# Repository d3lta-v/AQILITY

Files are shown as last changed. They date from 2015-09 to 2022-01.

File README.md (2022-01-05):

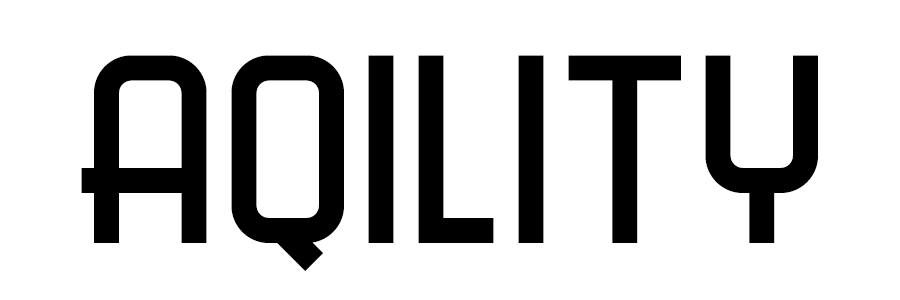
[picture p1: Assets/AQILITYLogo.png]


by StatiX Electromechanics, a subsidiary company of [StatiX Industries](https://statixind.net)

# AQILITY (Air Quality Acquisition Ability)

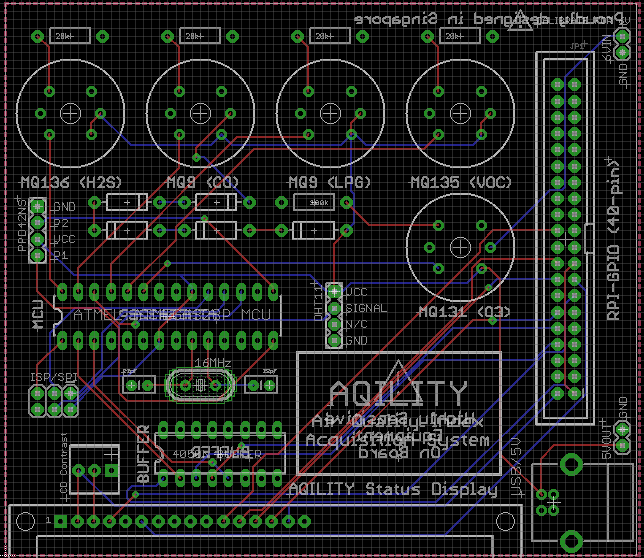
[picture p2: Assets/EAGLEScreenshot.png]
AQILITY


This is the open source version of the AQILITY, the free, crowd-sourced software and hardware platform for air quality detection and the upload of data to the cloud. We were simply people who thought we could do something about the Singapore/Indonesian transboundary haze, and this is what we've made. Enjoy!

#### How to access live data from the currently deployed sensor:

**Live** data which is processed by the MATLAB program included in this repo can be accessed on ThingSpeak [here](https://thingspeak.com/channels/56281). NOTE: The picture below is NOT the actual live data.

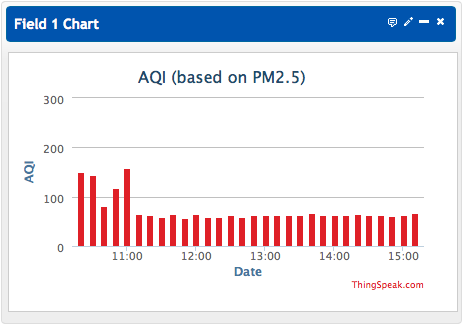
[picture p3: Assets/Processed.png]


Raw data (which may have errors) can be accessed [here](https://thingspeak.com/channels/31799), below is a sample of what to expect (this data is unprocessed and flawed, so please do not use this as official readings).

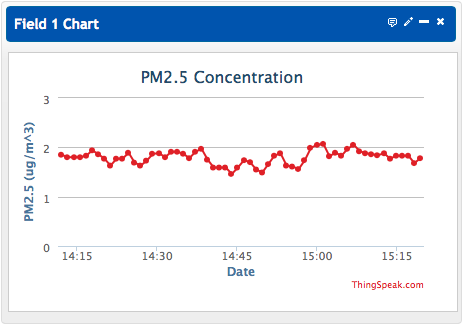
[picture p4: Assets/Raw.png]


The AVR subsysem of this system uses a forked version of the [DustDuino](http://publiclab.org/wiki/dustduino) code base (licensed under the CC BY-SA 3.0 license) for an Arduino-compatible particulate sensing system. Big props to them for doing the best work in the world.

## Description:
This system collects real time data from the air with several onboard sensors and relays the data from the microcontroller to the Raspberry Pi which caches all the data collected. This data is periodically uploaded onto the ThingSpeak platform, which is then analysed by the MATLAB code and the new data inserted into another ThingSpeak channel to display the actual values.

The calculation from ug/m<sup>3</sup> to official AQI is a piecewise linear function provided by the EPA (research paper [here](http://www3.epa.gov/ttn/oarpg/t1/memoranda/rg701.pdf)). The system provides an LCD screen to display live unprocessed values for easy monitoring.

A full flowchart of the system can be seen as below:

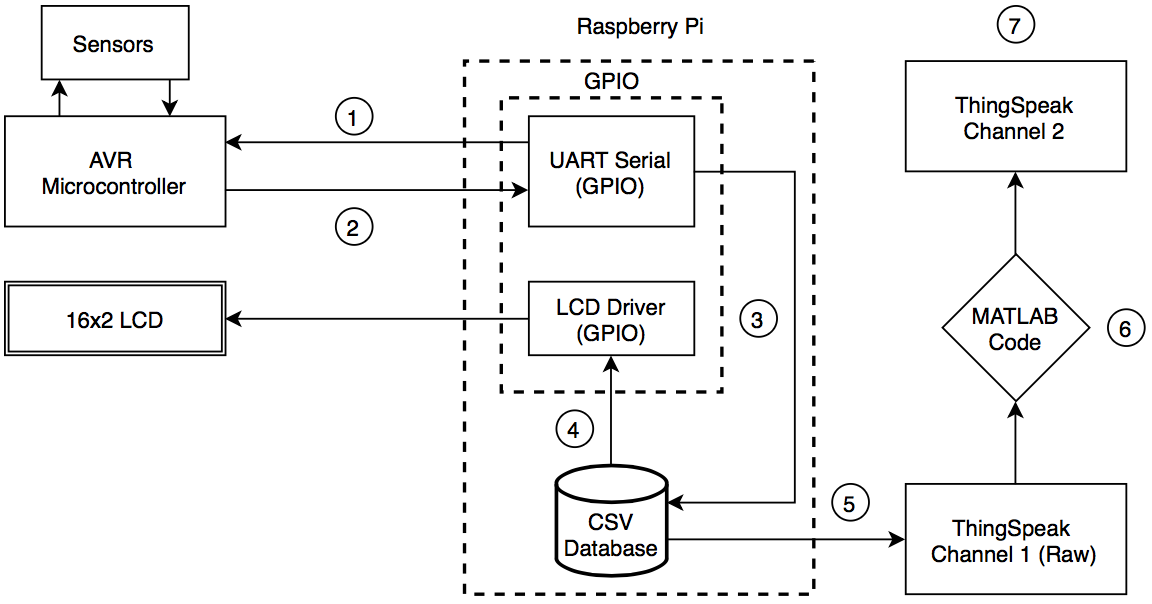
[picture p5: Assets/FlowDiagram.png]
Flowchart


1. Raspberry Pi sends a single unique character (a single dot, ".", ASCII code 46) to the microcontroller
2. Microcontroller has a cached copy of all the recent data taken over a certain timeframe and sends the cached data to the Pi. This data is already formatted in the CSV format.
3. Pi saves the data from the microcontroller into a CSV database.
4. The CSV database is read by another program and the data fed into the LCD driver on the GPIO to display air quality parameters on the LCD
5. Simultaneously, this data is sent by a HTTP POST request to the first ThingSpeak channel, which contains unprocessed data.
6. Data crunching takes place on the ThingSpeak platform with the MATLAB language, which calculates the correct AQI value using a piecewise linear function defined by the EPA.
7. The processed data is sent to the second ThingSpeak channel which houses all the processed data.

#### Features:

1. Has an LCD to display the air quality parameters dynamically on the sensor board itself
2. Automatically uploads air quality data to the cloud (ThingSpeak.com)
3. Relies on a Arduino-Raspberry Pi hybrid to achieve both long term data storage and better data transfer options such as through a cellular/3G USB dongle
4. Detects some of the most common airborne pollutants and chemicals (PM10, PM2.5, H2S, CO, VOCs) for the computation of the overall pollutant indices
5. The system has an initial waiting time, to wait for the AVR and the sensors to initialize and self-calibrate before taking readings.

## Availability:
This system is only tested on Raspberry Pis and the ATmega328P chip. There will be no guarentees that the same code (built on the Arduino platform) will run properly on other Arduino platforms or even on other AVRs such as the XMega series. The ribbon cable connector on the offical board is customized for Raspberry Pi + series ONLY, but you can manually pinout the connector for the old 28-pin GPIO.

## Author(s):
* Chief Designer; Programmer: Pan Ziyue
* R&D/Scientific Inquiry: Chow Zi Jie & Rachit Agrwal
* The awesome open source folks at Adafruit and the [DustDuino Development Team](http://publiclab.org/wiki/dustduino)

## Caveats:
* Requires for the Raspberry Pi's UART port on the GPIO to be freed. More info [here](http://www.hobbytronics.co.uk/raspberry-pi-serial-port)
* The code on the AVR seems to have a discrepancy of a factor of 10 for the PM2.5 concentration, which is then manually rectified by the MATLAB code. There may be a serious underlying problem with the original DustDuino code for the calculation of concentration, or lack of calibration of the sensor (which is supposed to be factory calibrated)
* The use of a Raspberry Pi enforces the use of a 5V/3.3V logic level shifter to avoid damaging the Pi.
* The gas sensors have NO calibration, which means that there is currently no logic implemented for the equation of output voltage of gas sensors to corresponding concentrations of gases.
* The Python code on the Raspberry Pi does not automatically archive or delete old data, and requires manual work to clear old data. This is a possible area of improvement and we welcome you to submit a pull request to implement such a feature.
* Dependencies must be manually installed and the GPIO port manually configured, which reduces code reusability and portability. Suggest making a single shell script to accomplish all of that.
* Python scripts must be pre-specified in `/etc/rc.local` for it to automatically start when the Raspberry Pi is booted up.

##  Dependencies:
* [Adafruit_Python_CharLCD](https://github.com/adafruit/Adafruit_Python_CharLCD)
* [DHT11 Library](http://playground.arduino.cc/Main/DHT11Lib)
* PySerial (install with `sudo pip3 install pyserial`)
* [httplib2](https://github.com/jcgregorio/httplib2)

## License:
<br />This work is licensed under a <a rel="license" href="http://creativecommons.org/licenses/by-sa/3.0/">Creative Commons Attribution-ShareAlike 3.0 Unported License</a>.

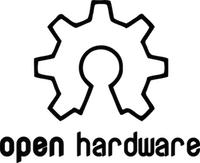
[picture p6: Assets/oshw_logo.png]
Open Source Hardware Initiative


Copyright (C) StatiX Industries 2014-2016

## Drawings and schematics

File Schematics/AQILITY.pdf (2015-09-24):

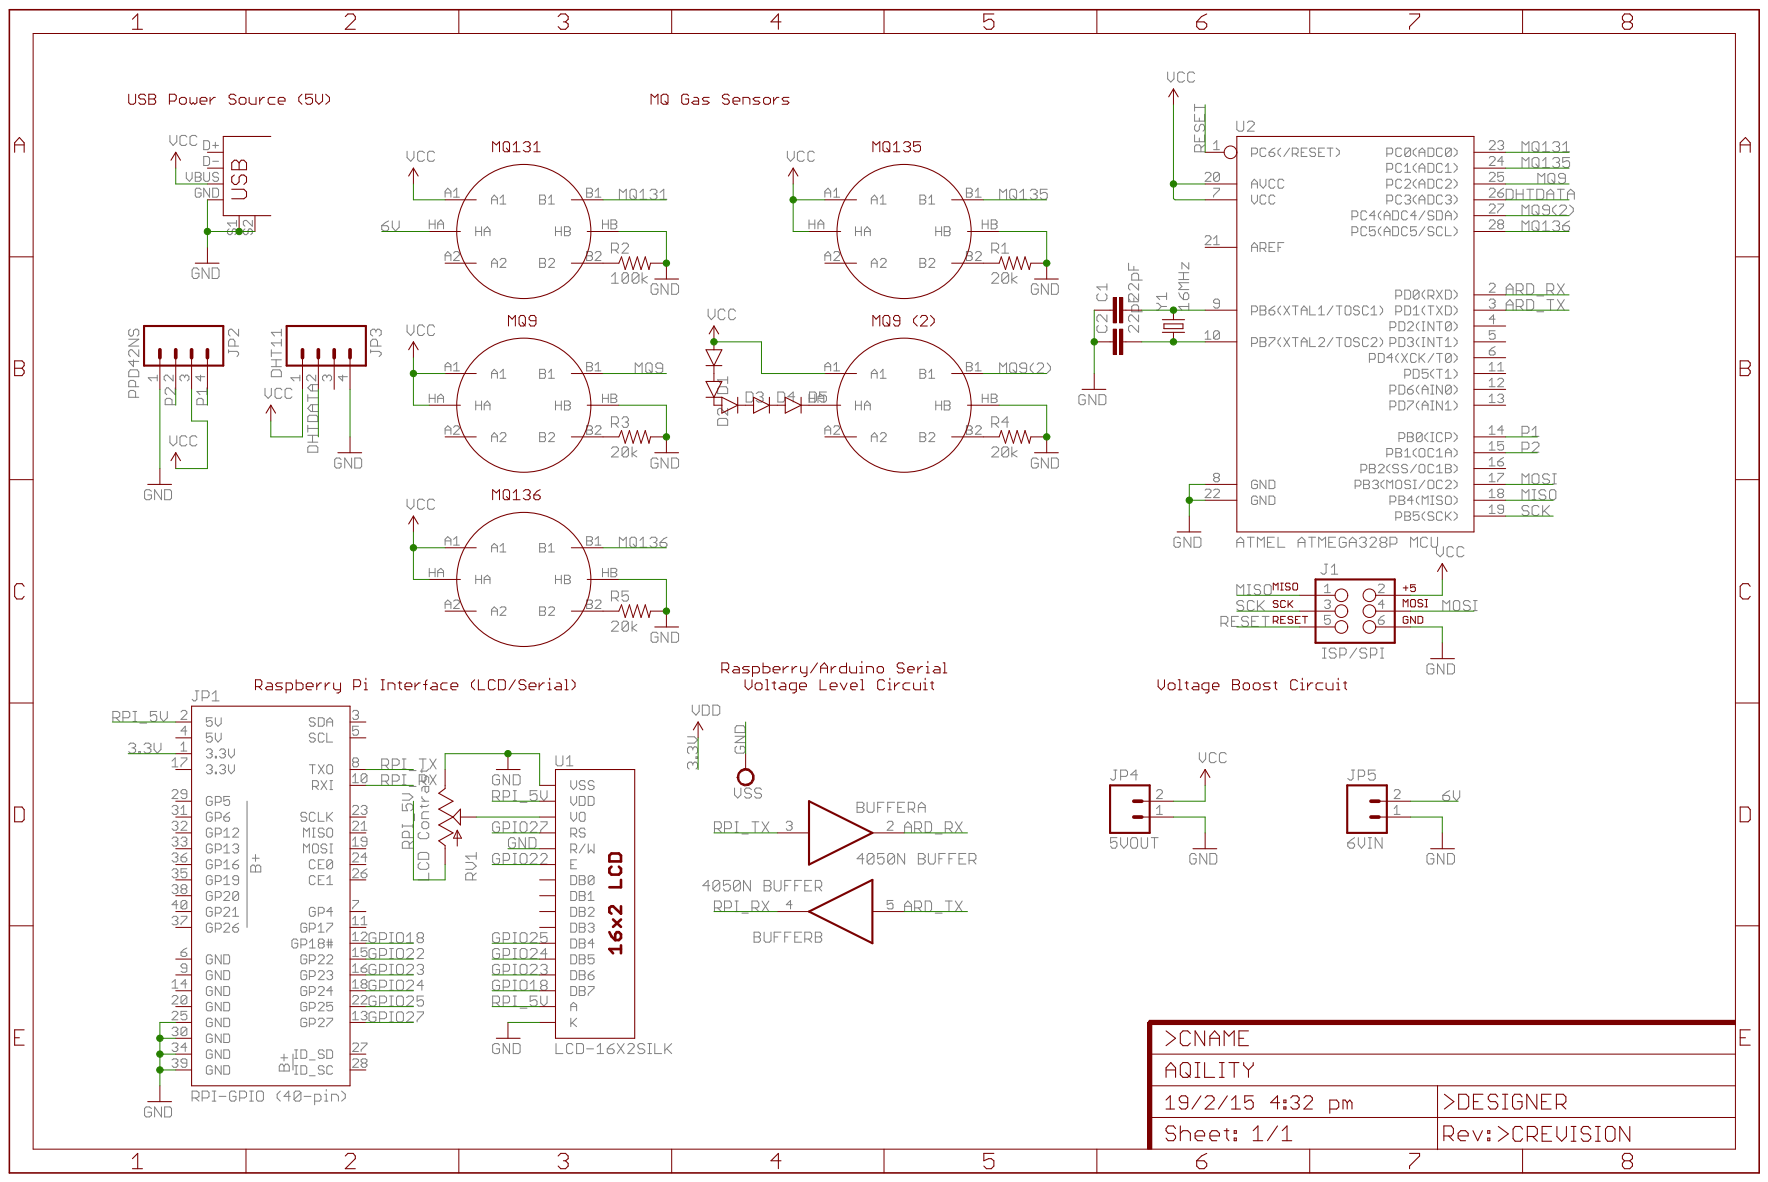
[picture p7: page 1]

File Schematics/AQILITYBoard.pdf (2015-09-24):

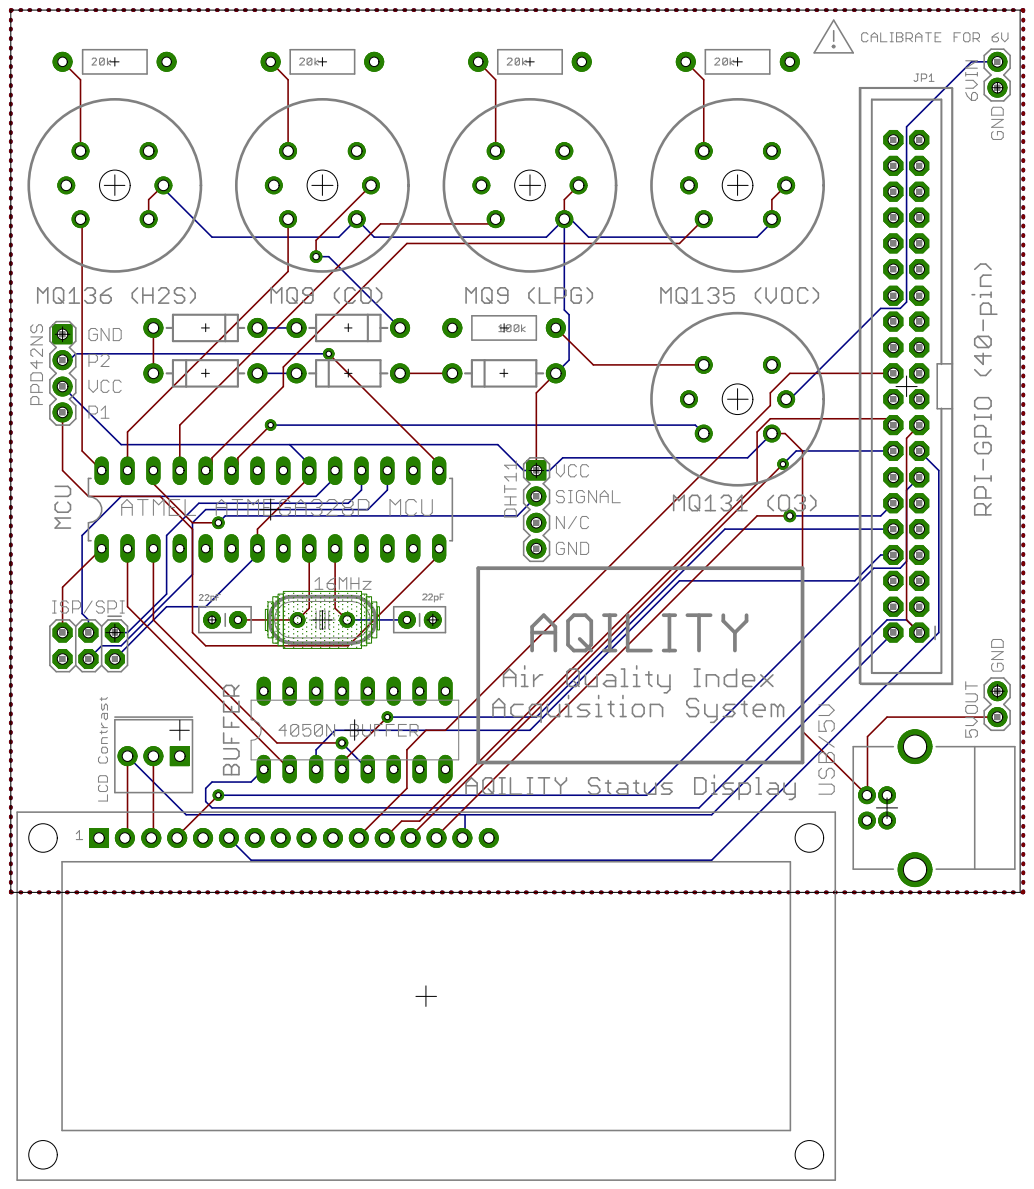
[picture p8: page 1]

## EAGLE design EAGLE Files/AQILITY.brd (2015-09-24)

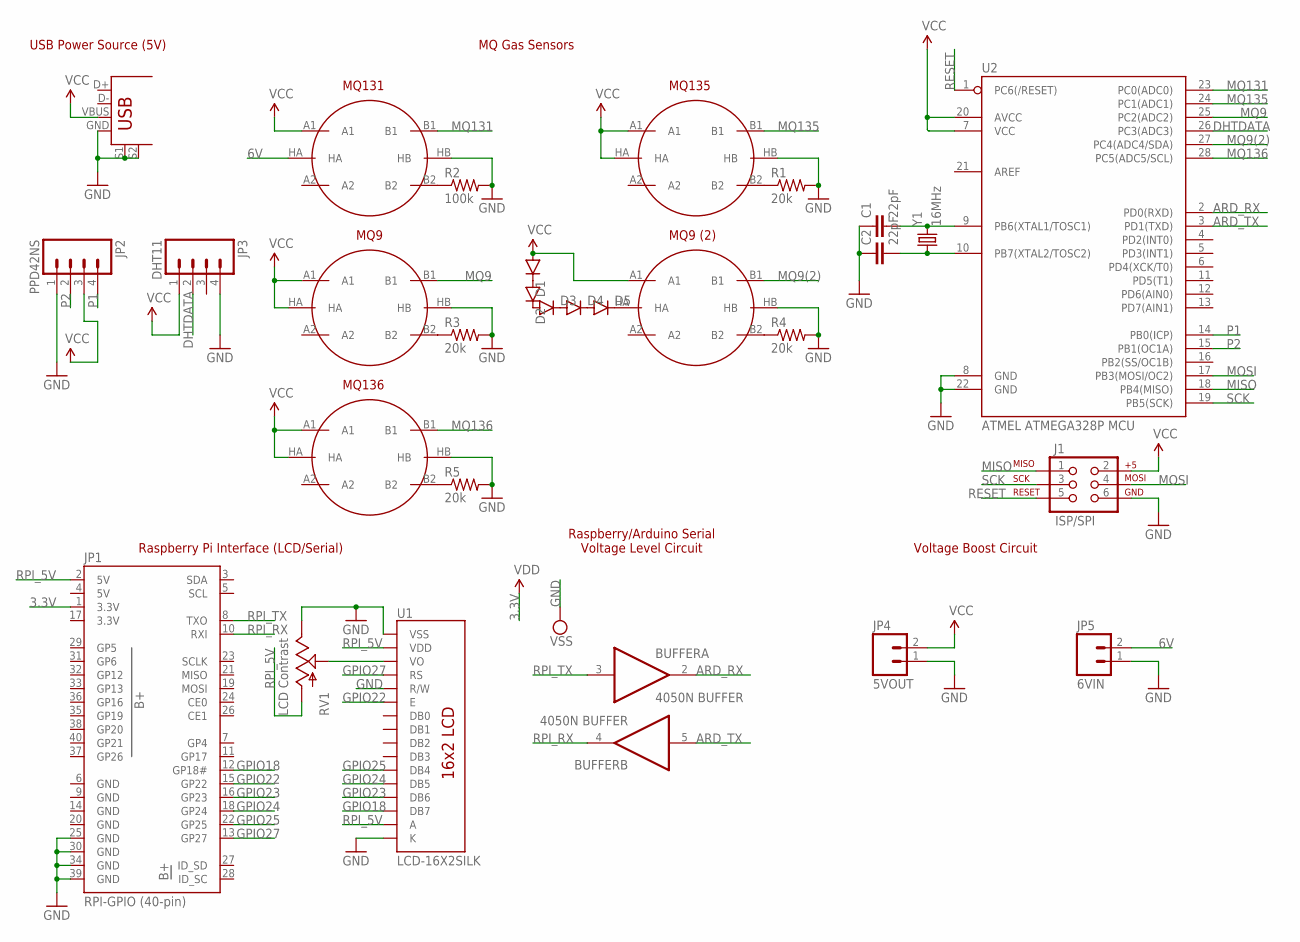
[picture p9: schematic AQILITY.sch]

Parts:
BUFFER: 4050N BUFFER; DIL16
C1, C2: 22pF; CAP-PTH-SMALLEZ
D1, D2, D3, D4, D5: DIODEKIT2; DIODE-1N4001-KIT
J1: ISP/SPI; 2X3
JP1: RPI-GPIO (40-pin); 2X20-SHROUDED
JP2: PPD42NS; 1X04
JP3: DHT11; 1X04
JP4: 5VOUT; 1X02
JP5: 6VIN; 1X02
MQ9, MQ9(2), MQ131, MQ135, MQ136: METHANE_SENSOR; MQ-3
R1, R3, R4, R5: 20k; AXIAL-0.4
R2: 100k; AXIAL-0.4
RV1: LCD Contrast; 3362U
U1: LCD-16X2SILK; LCD-16X2
U2: ATMEL ATMEGA328P MCU; DIL28-3
U$5: USB/5V; USB-B-PTH
Y1: 16MHz; HC49U-V

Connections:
3.3V: BUFFER.1 (VDD), JP1.1 (3.3V), JP1.17 (3.3V)
5V: JP1.4 (5V)
6V: JP5.2, MQ131.HA
ARD_RX: BUFFER.2 (O), U2.2 (PD0(RXD))
ARD_TX: BUFFER.5 (I), U2.3 (PD1(TXD))
DHTDATA: JP3.2, U2.26 (PC3(ADC3))
GND: BUFFER.8 (VSS), C1.1, C2.1, J1.6, JP1.6 (GND), JP1.9 (GND), JP1.14 (GND), JP1.20 (GND), JP1.25 (GND), JP1.30 (GND), JP1.34 (GND), JP1.39 (GND), JP2.1, JP3.4, JP4.1, JP5.1, MQ9.HB, MQ9(2).HB, MQ131.HB, MQ135.HB, MQ136.HB, R1.P$2 (2), R2.P$2 (2), R3.P$2 (2), R4.P$2 (2), R5.P$2 (2), RV1.P$1 (E), U1.1 (VSS), U1.5 (R/W), U1.16 (K), U2.8 (GND), U2.22 (GND), U$5.GND, U$5.S1, U$5.S2
GPIO18: JP1.12 (GP18#), U1.14 (DB7)
GPIO22: JP1.15 (GP22), U1.6 (E)
GPIO23: JP1.16 (GP23), U1.13 (DB6)
GPIO24: JP1.18 (GP24), U1.12 (DB5)
GPIO25: JP1.22 (GP25), U1.11 (DB4)
GPIO27: JP1.13 (GP27), U1.4 (RS)
MISO: J1.1, U2.18 (PB4(MISO))
MOSI: J1.4, U2.17 (PB3(MOSI/OC2))
MQ9: MQ9.B1, U2.25 (PC2(ADC2))
MQ9(2): MQ9(2).B1, U2.27 (PC4(ADC4/SDA))
MQ131: MQ131.B1, U2.23 (PC0(ADC0))
MQ135: MQ135.B1, U2.24 (PC1(ADC1))
MQ136: MQ136.B1, U2.28 (PC5(ADC5/SCL))
unnamed: RV1.P$2 (S), U1.3 (VO)
unnamed: C1.2, U2.9 (PB6(XTAL1/TOSC1)), Y1.2
unnamed: C2.2, U2.10 (PB7(XTAL2/TOSC2)), Y1.1
unnamed: D1.C, D2.A
unnamed: D2.C, D3.A
unnamed: D3.C, D4.A
unnamed: D5.C, MQ9(2).HA
unnamed: D4.C, D5.A
unnamed: MQ136.B2, R5.P$1 (1)
unnamed: MQ135.B2, R1.P$1 (1)
unnamed: MQ9.B2, R3.P$1 (1)
unnamed: MQ131.B2, R2.P$1 (1)
unnamed: MQ9(2).B2, R4.P$1 (1)
P1: JP2.4, U2.14 (PB0(ICP))
P2: JP2.2, U2.15 (PB1(OC1A))
RESET: J1.5, U2.1 (PC6(/RESET))
RPI_5V: JP1.2 (5V), RV1.P$3 (A), U1.2 (VDD), U1.15 (A)
RPI_RX: BUFFER.4 (O), JP1.10 (RXI)
RPI_TX: BUFFER.3 (I), JP1.8 (TXO)
SCK: J1.3, U2.19 (PB5(SCK))
VCC: D1.A, J1.2, JP2.3, JP3.1, JP4.2, MQ9.A1, MQ9.HA, MQ9(2).A1, MQ131.A1, MQ135.A1, MQ135.HA, MQ136.A1, MQ136.HA, U2.7 (VCC), U2.20 (AVCC), U$5.VBUS

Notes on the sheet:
MQ135
MQ131
MQ9
MQ9 (2)
MQ136
Voltage Boost Circuit
Raspberry Pi Interface (LCD/Serial)
MQ Gas Sensors
USB Power Source (5V)
Raspberry/Arduino Serial Voltage Level Circuit

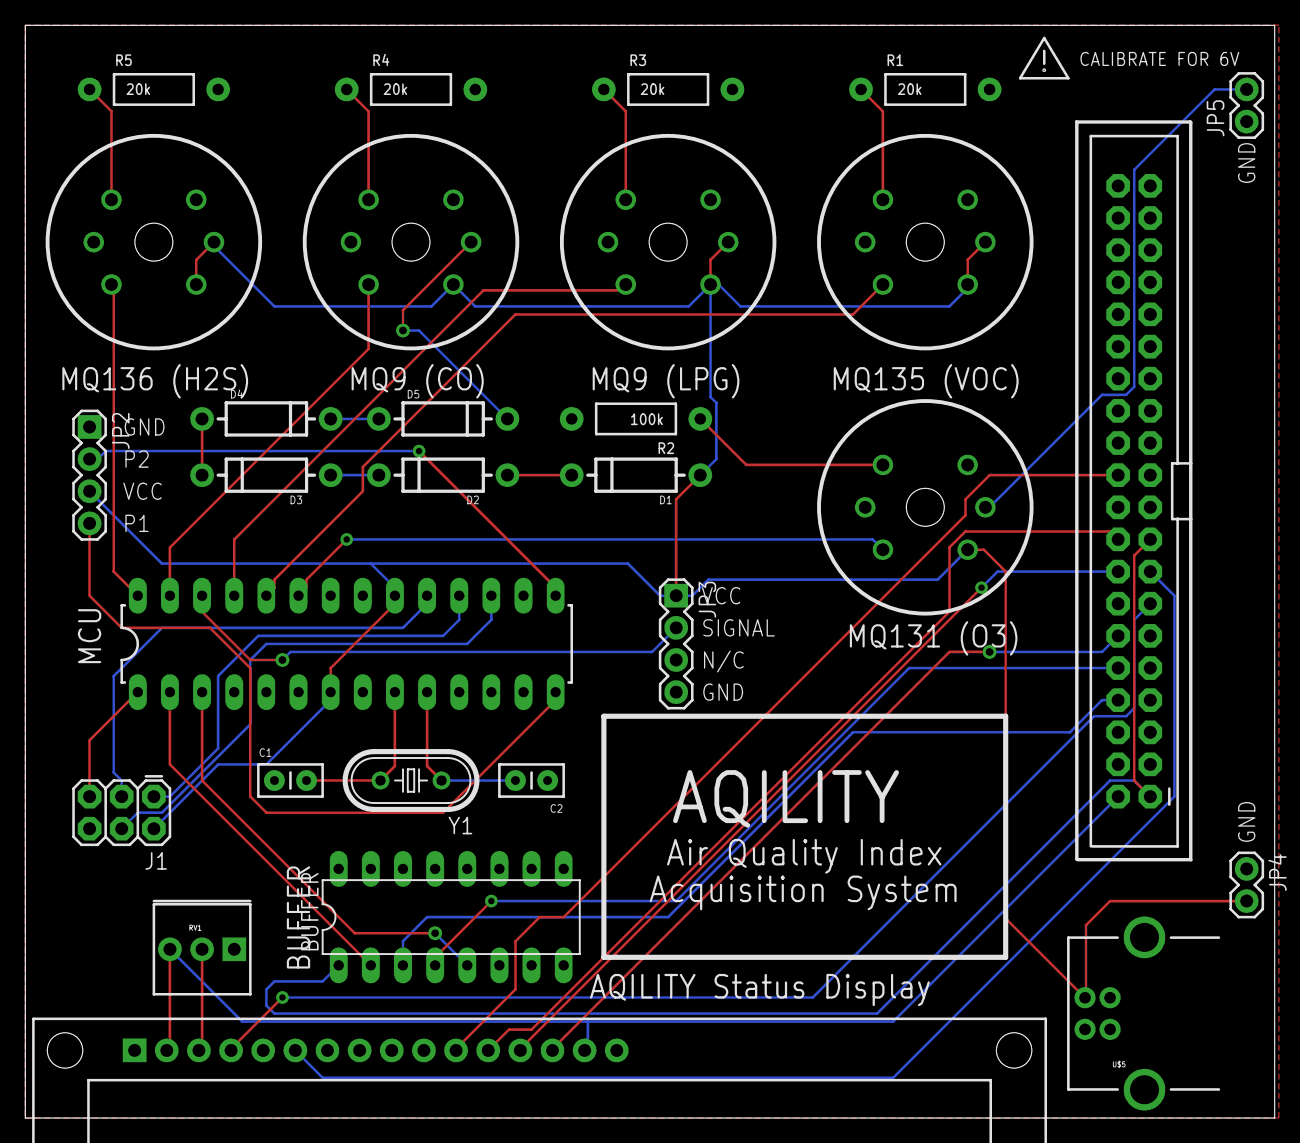
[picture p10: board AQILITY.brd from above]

Board: 2 copper layers, 98.7 x 86.3 mm, 29 parts (0 on the bottom side), 40 nets.

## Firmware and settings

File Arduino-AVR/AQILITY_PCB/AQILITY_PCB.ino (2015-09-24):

// 
// AQILITY (Air Quality Index Aquisition Ability)
// Created by Pan Ziyue and Chow Zijie 2014
// 

#include "dht11.h"

/* Start RainSensor/TempSensor */
const int numReadings = 10;
const int frequency = 1;    // How many probes per second?
const int caliOff = -10;

dht11 DHT11;
/* End RainSensor/TempSensor */

/* Start PinNames */
const int mq131Pin = A0;
const int mq135Pin = A1;
const int mq9Pin = A2; // Flammable gases
const int dhtPin = A3;
const int mq92Pin = A4; // Carbon monoxide
const int mq136Pin = A5; // Hydrogen Sulfide (H2S)
const int p1Pin = 8;
const int p2Pin = 9;
/* End PinNames */

/* Start SensorValues */
float mq131Voltage;
float mq135Voltage;
float mq9Voltage;
float mq92Voltage;
float mq136Voltage;

int humidityReadings[10];
int humidityIndex = 0;
int humidityTotal = 0;
int humidityAverage = 0;
float temperature = 0.0;
float humidity = 0.0;
/* End SensorValues*/

/* Start DustDuino Variable Import */
unsigned long starttime;

unsigned long triggerOnP1;
unsigned long triggerOffP1;
unsigned long pulseLengthP1;
unsigned long durationP1;
boolean valP1 = HIGH;
boolean triggerP1 = false;

unsigned long triggerOnP2;
unsigned long triggerOffP2;
unsigned long pulseLengthP2;
unsigned long durationP2;
boolean valP2 = HIGH;
boolean triggerP2 = false;

float ratioP1 = 0;
float ratioP2 = 0;
unsigned long sampletime_ms = 30000;
float countP1;
float countP2;

float concLarge=0.0;
float concSmall=0.0;

// Averaging variables starts here
float pm25Readings[5];
int pm25Index = 0;
float pm25Total = 0.0;
float pm25Average = 0.0;
float pm10Readings[5];
int pm10Index = 0;
float pm10Total = 0.0;
float pm10Average = 0.0;
/* End DustDuino Variable Import */

/* Start Serial Essentials */
int incomingByte = 0;
/* End Serial Essentials */

void setup() {
  // Init serial
  Serial.begin(9600);
  
  // Set pinMode just in case
  pinMode(dhtPin,INPUT);
  pinMode(p1Pin,INPUT);
  pinMode(p2Pin,INPUT);
  
  // Initial read of temperature and humidity from the sensor.
  // May take up to 20 seconds before the Arduino responds
  for (int i=0; i<10; i++) {
    temperatureAndHumidityUpdate();
  }
}

void loop() {
  // Retreive all data from sensors here (except from DHT11)
  getDustData();
  mq131Voltage = (analogRead(mq131Pin)/1024.0)*5.0;
  mq135Voltage = (analogRead(mq135Pin)/1024.0)*5.0;
  mq9Voltage = (analogRead(mq9Pin)/1024.0)*5.0;
  mq92Voltage = (analogRead(mq92Pin)/1024.0)*5.0;
  mq136Voltage = (analogRead(mq136Pin)/1024.0)*5.0;
  
  // Check for RPi asking for serial data transmission
  incomingByte = Serial.read();
  // Begin serial data transmission, 9600 baud
  if (incomingByte == 46) {
    temperatureAndHumidityUpdate(); // This takes very long (read from DHT11)
    Serial.print(mq131Voltage);
    Serial.print(",");
    Serial.print(mq135Voltage);
    Serial.print(",");
    Serial.print(mq9Voltage);
    Serial.print(",");
    Serial.print(mq92Voltage);
    Serial.print(",");
    Serial.print(mq136Voltage);
    Serial.print(",");
    Serial.print(pm25Average);
    Serial.print(",");
    Serial.print(pm10Average);
    Serial.print(",");
    // Calculate AQI rating
    //Serial.print("AQI: ");
    if (pm25Average>250.0 || pm10Average>420.0) {
      Serial.print("HAZARDOUS");
    } else if ((pm25Average<=250.0 && pm25Average>150.0) || (pm10Average<=420.0 && pm10Average>350.0)) {
      Serial.print("Very Unhealthy");
    } else if ((pm25Average<=150.0 && pm25Average>55.0) || (pm10Average<=350.0 && pm10Average>150.0)) {
      Serial.print("Unhealthy");
    } else if ((pm25Average<=55.0 && pm25Average>12.0) || (pm10Average<=150.0 && pm10Average>50.0)) {
      Serial.print("Moderate");
    } else if (pm25Average<=12.0 && pm10Average<=50.0) {
      Serial.print("Good");
    }
    Serial.print(",");
    Serial.print(temperature);
    Serial.print(",");
    Serial.println(humidity);
  }  
}

void temperatureAndHumidityUpdate() {
  switch(DHT11.read(dhtPin)) {
    case DHTLIB_OK: break;
    case DHTLIB_ERROR_CHECKSUM:
      //Serial.println("Error Checksum!!");
      goto fail;
      break;
    case DHTLIB_ERROR_TIMEOUT:
      //Serial.println("Error Timeout!!");
      goto fail;
      break;
    default:
      //Serial.println("Unknown Error!!");
      goto fail;
      break;
  }
  
  humidityTotal= humidityTotal - humidityReadings[humidityIndex];
  humidityReadings[humidityIndex] = DHT11.humidity;
  humidityTotal= humidityTotal + humidityReadings[humidityIndex];
  humidityIndex = humidityIndex + 1;
  if (humidityIndex >= numReadings)
    humidityIndex = 0;
  humidityAverage = humidityTotal / numReadings;
  
  temperature = DHT11.temperature;
  humidity = humidityAverage;
  
  fail: // Failed probe, skip all code and repeat
  delay((int)1000/frequency);
}

void getDustData() {
  valP1 = digitalRead(p1Pin); // Digital Pin 8
  valP2 = digitalRead(p2Pin); // Digital Pin 9
  
  if(valP1 == LOW && triggerP1 == false){
    triggerP1 = true;
    triggerOnP1 = micros();
  }
  
  if (valP1 == HIGH && triggerP1 == true){
    triggerOffP1 = micros();
    pulseLengthP1 = triggerOffP1 - triggerOnP1;
    durationP1 = durationP1 + pulseLengthP1;
    triggerP1 = false;
  }
  
  if(valP2 == LOW && triggerP2 == false){
    triggerP2 = true;
    triggerOnP2 = micros();
  }
  
  if (valP2 == HIGH && triggerP2 == true){
    triggerOffP2 = micros();
    pulseLengthP2 = triggerOffP2 - triggerOnP2;
    durationP2 = durationP2 + pulseLengthP2;
    triggerP2 = false;
  }
    
  if ((millis() - starttime) > sampletime_ms) {
    ratioP1 = durationP1/(sampletime_ms*10.0);  // Integer percentage 0=>100
    ratioP2 = durationP2/(sampletime_ms*10.0);
    countP1 = 1.1*pow(ratioP1,3)-3.8*pow(ratioP1,2)+520*ratioP1+0.62;
    countP2 = 1.1*pow(ratioP2,3)-3.8*pow(ratioP2,2)+520*ratioP2+0.62;
    float PM10count = countP2;
    float PM25count = countP1 - countP2;
    
    // Avoid wasting computational cycles by not processing bad data
    if (PM10count > 0.62) {
      // first, PM10 count to mass concentration conversion
      double r10 = 2.6*pow(10,-6);
      double pi = 3.14159;
      double vol10 = (4/3)*pi*pow(r10,3);
      double density = 1.65*pow(10,12);
      double mass10 = density*vol10;
      double K = 3531.5;
      
      // next, PM2.5 count to mass concentration conversion
      double r25 = 0.44*pow(10,-6);
      double vol25 = (4/3)*pi*pow(r25,3);
      double mass25 = density*vol25;
      
      concLarge = (PM10count)*K*mass10;
      concSmall = (PM25count)*K*mass25;
      
      // Calculating averages here
      pm25Total = pm25Total - pm25Readings[pm25Index];
      pm25Readings[pm25Index] = concSmall;
      pm25Total = pm25Total + pm25Readings[pm25Index];
      pm25Index++;
      if (pm25Index >= 5)
        pm25Index=0;
      pm25Average = pm25Total/5;
      
      pm10Total = pm10Total - pm10Readings[pm10Index];
      pm10Readings[pm10Index] = concLarge;
      pm10Total = pm10Total + pm10Readings[pm10Index];
      pm10Index++;
      if (pm10Index >= 5)
        pm10Index=0;
      pm10Average = pm10Total/5;
    }
  
    durationP1 = 0;
    durationP2 = 0;
    starttime = millis();
  }
}

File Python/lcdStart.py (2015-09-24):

#!/usr/bin/python
# lcdStart.py Python Code (part of the AQILITY project)
# This script *SHOULD* be started on boot
# This script also contains code for the automatic upload of raw data to ThingSpeak
# Script requires the following dependencies:
# 1. Adafruit_CharLCD
# 2. httplib2
import math
import time
import Adafruit_CharLCD as LCD
import csv
import signal
import sys
from urllib import urlencode
from httplib2 import Http

# Raspberry Pi pin configuration:
lcd_rs        = 27  # Note this might need to be changed to 21 for older revision Pi's.
lcd_en        = 22
lcd_d4        = 25
lcd_d5        = 24
lcd_d6        = 23
lcd_d7        = 18
lcd_backlight = 4

# Define LCD column and row size for 16x2 LCD.
lcd_columns = 16
lcd_rows    = 2

# Alternatively specify a 20x4 LCD.
# lcd_columns = 20
# lcd_rows    = 4

# Initialize the LCD using the pins above.
lcd = LCD.Adafruit_CharLCD(lcd_rs, lcd_en, lcd_d4, lcd_d5, lcd_d6, lcd_d7,
                            lcd_columns, lcd_rows, lcd_backlight)

lcd.clear()

# Print a dynamic message that spans one minute
for x in range(0,80):
    lcd.message('AQILITY v0.1b\nStarting up...')
    time.sleep(0.5)
    lcd.clear()
    lcd.message('AQILITY v0.1b\nStarting up.')
    time.sleep(0.5)
    lcd.clear()
    lcd.message('AQILITY v0.1b\nStarting up..')
    time.sleep(0.5)
    lcd.clear()

# Make SIGTERM handler to make the LCD look nicer when RPi is shutting down
def signal_term_handler(signal, frame):
    lcd.clear()
    lcd.message('AQILITY v0.1b\nShutting down')
    sys.exit(0)
signal.signal(signal.SIGTERM, signal_term_handler)

# Read from database and populate screen with data
lcd.clear()
# Reference database format: MQ131,MQ135,MQ9/1,MQ9/2,MQ136,PM2.5,PM10,AQI,TEMP,HUM
# Local variables in this dictionary:
localVariables = {'mq131Voltage':"",'mq135Voltage':"",'mq9Voltage':"",'mq92Voltage':"",'mq136Voltage':"",'pm25':"",'pm10':"",'AQI':"",'temp':"",'hum':""}
# Make function that counts lines in the CSV
def file_len(fname):
    with open(fname) as f:
        for i, l in enumerate(f):
            pass
    return i + 1

# Begin loop
while True:
    # Update all variables
    data = [row for row in csv.reader(open('database.csv', 'rb'))]
    fileLength = file_len('database.csv')
    localVariables['mq131Voltage']=data[fileLength-1][0]
    localVariables['mq135Voltage']=data[fileLength-1][1]
    localVariables['mq9Voltage']=data[fileLength-1][2]
    localVariables['mq92Voltage']=data[fileLength-1][3]
    localVariables['mq136Voltage']=data[fileLength-1][4]
    localVariables['pm25']=data[fileLength-1][5]
    localVariables['pm10']=data[fileLength-1][6]
    localVariables['AQI']=data[fileLength-1][7]
    localVariables['temp']=data[fileLength-1][8]
    localVariables['hum']=data[fileLength-1][9]
    try:
        h = Http()
        #TODO: insert ThingSpeak API key here, previous key redacted for security reasons
        data = dict(key="",
        field1=localVariables['pm25'],
        field2=localVariables['pm10'],
        field3=localVariables['temp'],
        field4=localVariables['hum'],
        field5=localVariables['mq131Voltage'],
        field6=localVariables['mq135Voltage'],
        field7=localVariables['mq136Voltage'],
        field8=localVariables['mq92Voltage'])
        resp, content = h.request("http://api.thingspeak.com/update","POST",urlencode(data))
    except:
        lcd.message("NO INTERNET CONN\nNO DATA UPLOADED")
        time.sleep(5)
        lcd.clear()
    for r in range(0,2):
		# Show PM2.5+PM10+AQI
		for i in range(0,2):
			lcd.message("PM2.5:"+localVariables['pm25']+"\nPM10:"+localVariables['pm10'])
			time.sleep(2)
			lcd.clear()
			lcd.message("AQI Rating:\n"+localVariables['AQI'])
			time.sleep(2)
			lcd.clear()
		# Show MQ Gas Sensors:
		for i in range(0,2):
			lcd.message("MQ Gas Sensors:\n"+"MQ131(O3):"+localVariables['mq131Voltage']+"V")
			time.sleep(2)
			lcd.clear()
			lcd.message("MQ135(VOC):"+localVariables['mq135Voltage']+"V\n"+"MQ136(SO2):"+localVariables['mq136Voltage']+"V")
			time.sleep(2)
			lcd.clear()
			lcd.message("MQ9(LPG):"+localVariables['mq9Voltage']+"V\n"+"MQ9(CO):"+localVariables['mq92Voltage']+"V")
			time.sleep(2)
			lcd.clear()
		# Show DHT11 data
		for i in range(0,2):
			lcd.message("Temperature:\n"+localVariables['temp']+chr(223)+"C")
			time.sleep(2)
			lcd.clear()
			lcd.message("Humidity:\n"+localVariables['hum']+chr(37))
			time.sleep(2)
			lcd.clear()

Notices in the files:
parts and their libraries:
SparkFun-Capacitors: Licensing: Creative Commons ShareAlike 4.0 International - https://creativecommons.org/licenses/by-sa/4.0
